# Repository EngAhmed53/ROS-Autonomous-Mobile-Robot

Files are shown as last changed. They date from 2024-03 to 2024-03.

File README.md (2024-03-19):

# Autonomous Navigation Mobile Robot

## Table of Contents

1. [Introduction](#introduction)
2. [Demo](#demo)
3. [Motivations](#motivations)
4. [Roadmap](#roadmap)
5. [Design](#design)
6. [Source Code](#source-code)
7. [License](#license)

## Introduction
This project is based on the Udacity Home Service Robot project, the final project of the Udacity Robotics Nanodegree.

## Demo
[Youtube video](https://youtu.be/6-blbdkCTCw?si=ebP5qN-LpaIK6vIa)

## Motivations
I start working on this project for several reasons:
1. To apply the knowledge I gained from the nanodegree to a real robot.
2. To enhance my understanding of ROS (Robot Operating System).
3. To observe the robot's behavior in real-world scenarios.

## Roadmap
To complete this project, I divided it into the following steps:
1. Set up Raspberry Pi.
2. Establish an SSH connection with Raspberry Pi.
3. Run RPLidar on Raspberry Pi and visualize its data on the remote machine.
4. Implement the Arduino ROS Bridge.
5. Implement the ROS control nodes on Raspberry Pi.
6. Test control nodes using keyboard input.
7. Design and build the robot chassis.
8. Configure the mapping nodes.
9. Test the mapping.
10. Configure the navigation nodes.
11. Test autonomous navigation.
12. Enhancements and fixes.

## Design
The robot is a differential drive robot with two wheels at the back and a caster wheel at the front.
The robot's base consists of three layers made from wooden material, separated by 45mm spacers. Each layer includes various components:
1. The bottom layer contains motors, an Arduino UNO board, an L298N motor driver, and a breadboard for component interconnection.
2. The middle layer houses the Raspberry Pi 3 Model B and an XL4015 5A Step Down Module to power the Raspberry Pi.
3. The upper layer hosts the RPLidar, the Raspberry Pi Camera v1, and a 12v battery.

The robot has three sensors:
1. Motor encoders
2. RPLidar
3. Camera

<p align="center" width="100%">
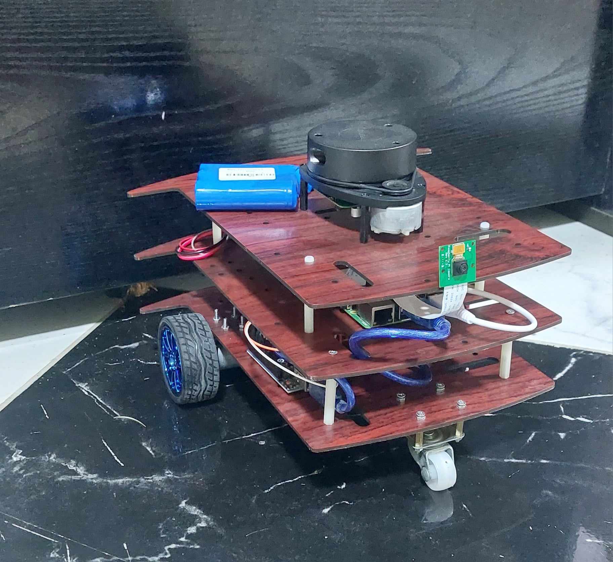
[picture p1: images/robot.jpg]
Robot
    
    <br>Robot Chassis
</p>

<p align="center" width="100%">
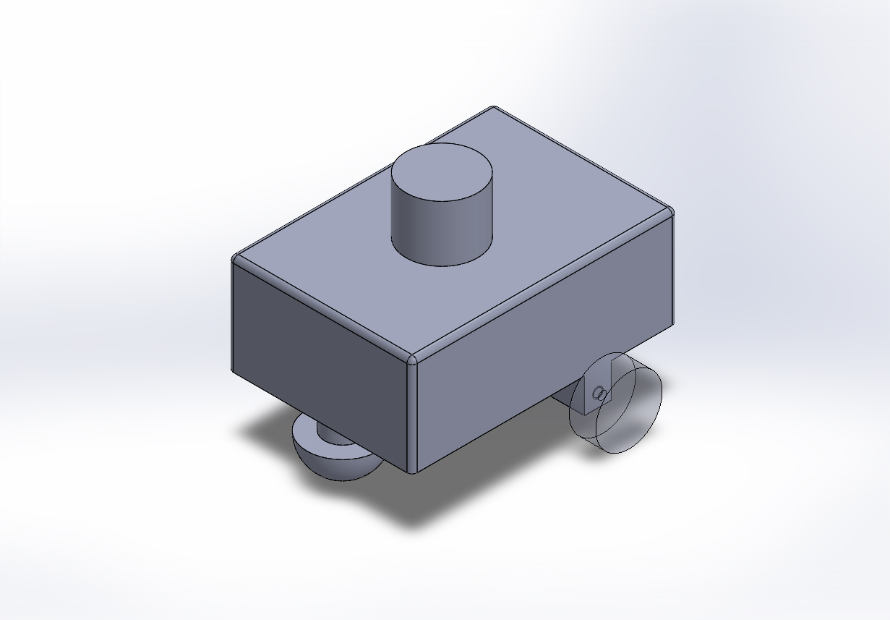
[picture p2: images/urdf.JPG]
    
    <br>Robot URDF
</p>

## Source Code

The robot uses a Raspberry Pi 3B. Due to its limited processing power, I've optimized its usage by offloading visualization and heavy computing tasks to a more powerful desktop computer. I used ROS networking to establish communication between the robot and the remote computer.

The Raspberry Pi manages the robot's sensors, such as the RPLidar and camera, by publishing their data to topics. Additionally, it controls the robot's movement by sending speed commands and receiving encoder readings from an Arduino board.

On the remote computer side, I handled visualization, mapping, and localization using SLAM (Simultaneous Localization and Mapping) and navigation nodes. For SLAM, I used the slam_gmapping node, while localization is achieved through the AMCL (Adaptive Monte Carlo Localization) node. Finally, autonomous navigation to the goal location is enabled using the move_base node.

The source code of the project is divided into three parts:
1. [The robot side](/Robot-Local): This code runs on the Raspberry Pi. The Raspberry Pi runs Ubuntu 20.04 with ROS Noetic [download link](https://learn.ubiquityrobotics.com/noetic_pi_image_downloads).
2. [The remote machine side](/Remote-Machine): This code runs on a remote computer.
3. [The Arduino ROS Bridge](https://github.com/EngAhmed53/ROS-Arduino-Bridge): This Arduino code runs on the Arduino UNO board. This code acts as a bridge between ROS and the motors.

## License
This project is licensed under the [MIT License](LICENSE).

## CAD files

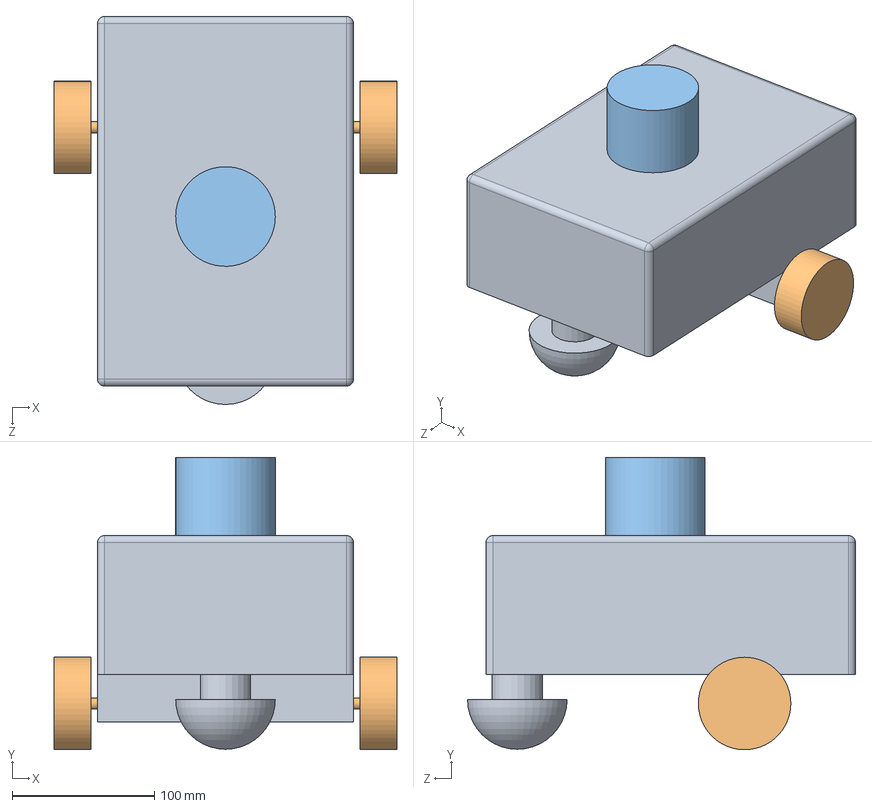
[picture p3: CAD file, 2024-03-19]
Design/robot_assem.SLDASM
241.0 x 205.5 x 272.6 mm
robot_base
robot_wheel x 2
rplidar_a1m12

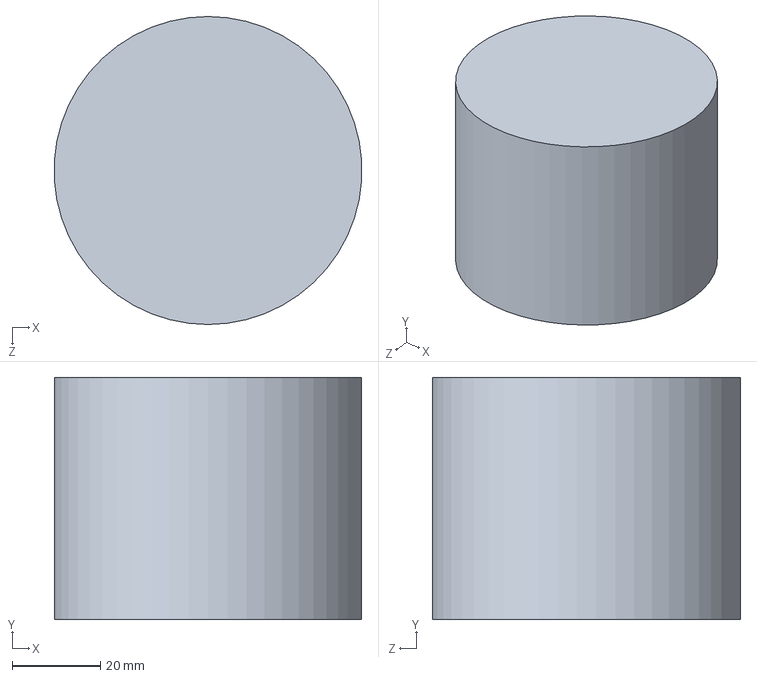
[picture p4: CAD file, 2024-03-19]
Design/rplidar_a1m12.SLDPRT
69.9 x 55.0 x 70.0 mm

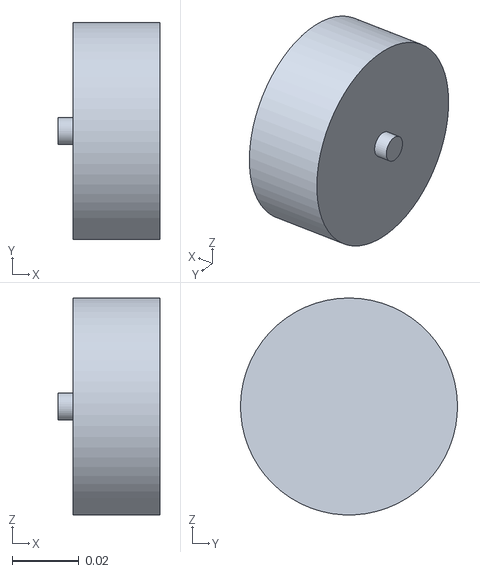
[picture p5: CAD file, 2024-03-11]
Robot-Local/src/my_robot/meshes/right_wheel.STL
0.0305 x 0.065 x 0.065

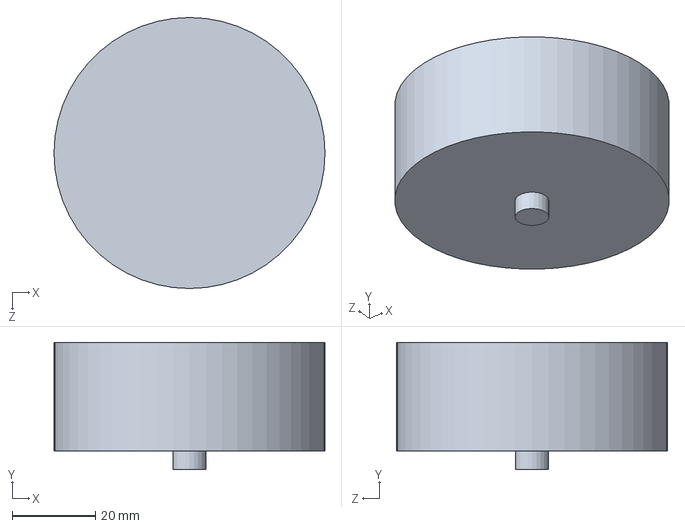
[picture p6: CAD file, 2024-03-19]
Design/robot_wheel.SLDPRT
65.0 x 30.5 x 65.0 mm

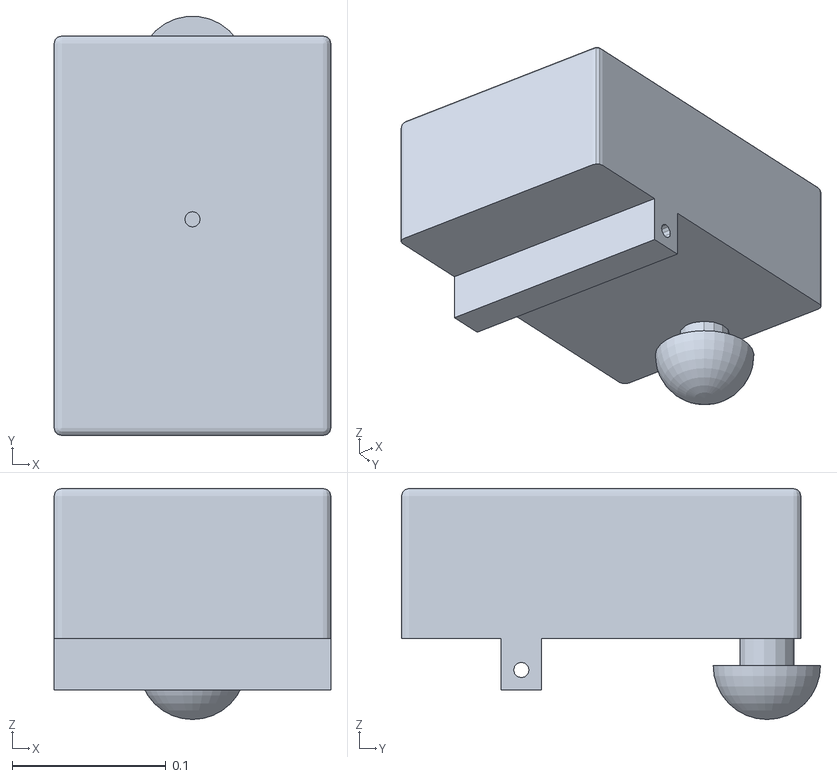
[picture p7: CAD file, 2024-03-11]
Robot-Local/src/my_robot/meshes/base_link.STL
0.18 x 0.272 x 0.15

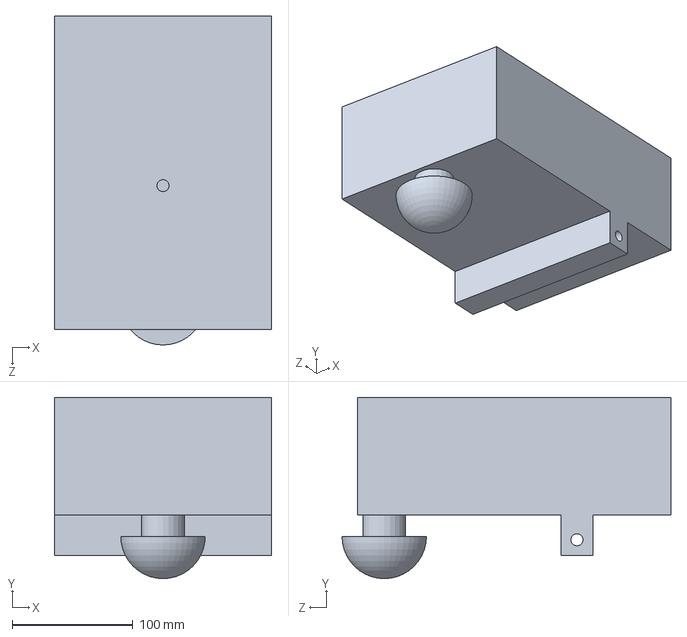
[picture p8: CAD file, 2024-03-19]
Design/robot_base.SLDPRT
180.0 x 150.2 x 272.6 mm

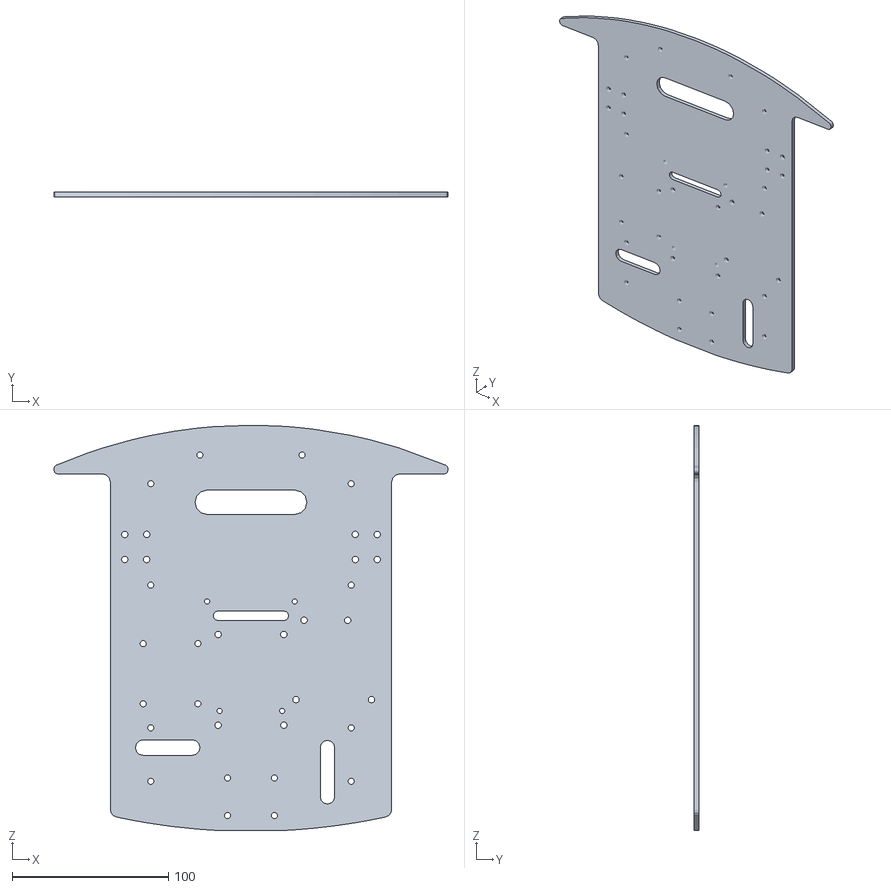
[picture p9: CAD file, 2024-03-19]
Design/robot_part_without_spacer.STL
252.0 x 3.00 x 259.3

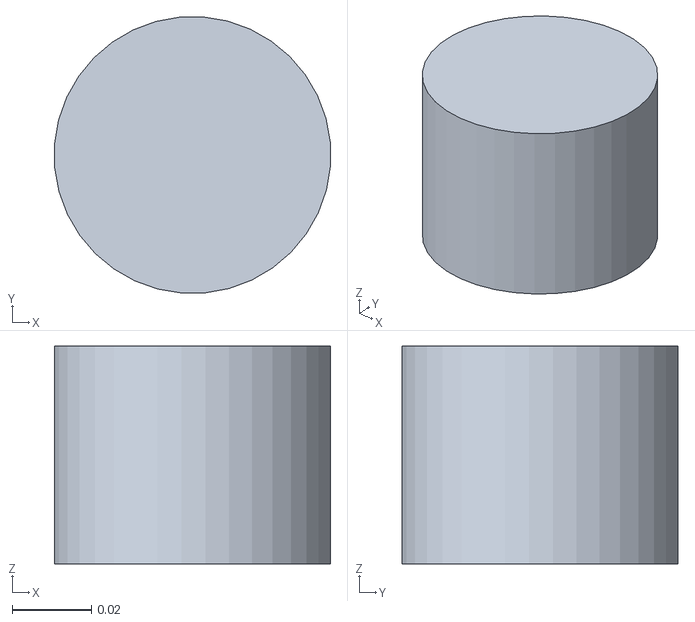
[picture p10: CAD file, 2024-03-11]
Robot-Local/src/my_robot/meshes/laser_link.STL
0.0698 x 0.0698 x 0.055

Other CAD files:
Robot-Local/src/my_robot/meshes/left_wheel.STL

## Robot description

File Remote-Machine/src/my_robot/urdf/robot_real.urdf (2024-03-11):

<?xml version="1.0" encoding="utf-8"?>
<!-- This URDF was automatically created by SolidWorks to URDF Exporter! Originally created by Stephen Brawner (brawner@gmail.com) 
     Commit Version: 1.6.0-4-g7f85cfe  Build Version: 1.6.7995.38578
     For more information, please see http://wiki.ros.org/sw_urdf_exporter -->
<robot name="robot_real">

  <link name="robot_footprint"></link>

  <joint name="robot_footprint_joint" type="fixed">
    <origin xyz="0 0 0" rpy="0 0 0" />
    <parent link="robot_footprint"/>
    <child link="base_link" />
  </joint>

  <link name="base_link">
    <inertial>
      <origin xyz="0 0.00086857 -0.052452" rpy="0 0 0" />
      <mass value="4.8015" />
      <inertia ixx="0.031989" ixy="-1.3236E-18" ixz="-6.8277E-21" iyy="0.017464" iyz="0.00037688" izz="0.039875" />
    </inertial>
    <visual>
      <origin xyz="0 0 0" rpy="0 0 0" />
      <geometry>
        <mesh filename="package://my_robot/meshes/base_link.STL" />
      </geometry>
      <material name="">
        <color rgba="0.79216 0.81961 0.93333 1" />
      </material>
    </visual>
    <collision>
      <origin xyz="0 0 0" rpy="0 0 0" />
      <geometry>
        <mesh filename="package://my_robot/meshes/base_link.STL" />
      </geometry>
    </collision>
  </link>
  <link name="laser_link">
    <inertial>
      <origin xyz="9.8765E-13 -7.5229E-13 -0.0275" rpy="0 0 0" />
      <mass value="0.21166" />
      <inertia ixx="0.00011818" ixy="1.6676E-21" ixz="-2.1229E-36" iyy="0.00011818" iyz="-3.1058E-21" izz="0.00012964" />
    </inertial>
    <visual>
      <origin xyz="0 0 0" rpy="0 0 0" />
      <geometry>
        <mesh filename="package://my_robot/meshes/laser_link.STL" />
      </geometry>
      <material name="">
        <color rgba="0.79216 0.81961 0.93333 1" />
      </material>
    </visual>
    <collision>
      <origin xyz="0 0 0" rpy="0 0 0" />
      <geometry>
        <mesh filename="package://my_robot/meshes/laser_link.STL" />
      </geometry>
    </collision>
  </link>
  <joint name="laser_joint" type="fixed">
    <origin xyz="0 0.010725 0.046" rpy="0 0 0" />
    <parent link="base_link" />
    <child link="laser_link" />
    <axis xyz="0 0 0" />
  </joint>
  <link name="left_wheel">
    <inertial>
      <origin xyz="0.01304 0 0" rpy="0 0 0" />
      <mass value="0.086502" />
      <inertia ixx="4.5566E-05" ixy="7.1534E-20" ixz="7.1695E-20" iyy="2.7696E-05" iyz="2.1146E-34" izz="2.7696E-05" />
    </inertial>
    <visual>
      <origin xyz="0 0 0" rpy="0 0 0" />
      <geometry>
        <mesh filename="package://my_robot/meshes/left_wheel.STL" />
      </geometry>
      <material name="">
        <color rgba="0.79216 0.81961 0.93333 1" />
      </material>
    </visual>
    <collision>
      <origin xyz="0 0 0" rpy="0 0 0" />
      <geometry>
        <mesh filename="package://my_robot/meshes/left_wheel.STL" />
      </geometry>
    </collision>
  </link>
  <joint name="left_wheel_joint" type="continuous">
    <origin xyz="-0.1205 -0.051915 -0.118" rpy="0 0 0" />
    <parent link="base_link" />
    <child link="left_wheel" />
    <axis xyz="1 0 0" />
    <limit effort="0" velocity="2" />
  </joint>
  <link name="right_wheel">
    <inertial>
      <origin xyz="-0.01304 -4.4409E-16 2.2204E-16" rpy="0 0 0" />
      <mass value="0.086502" />
      <inertia ixx="4.5566E-05" ixy="1.7026E-19" ixz="-7.1695E-20" iyy="2.7696E-05" iyz="-7.8374E-34" izz="2.7696E-05" />
    </inertial>
    <visual>
      <origin xyz="0 0 0" rpy="0 0 0" />
      <geometry>
        <mesh filename="package://my_robot/meshes/right_wheel.STL" />
      </geometry>
      <material name="">
        <color rgba="0.79216 0.81961 0.93333 1" />
      </material>
    </visual>
    <collision>
      <origin xyz="0 0 0" rpy="0 0 0" />
      <geometry>
        <mesh filename="package://my_robot/meshes/right_wheel.STL" />
      </geometry>
    </collision>
  </link>
  <joint name="right_wheel_joint" type="continuous">
    <origin xyz="0.1205 -0.051915 -0.118" rpy="0 0 0" />
    <parent link="base_link" />
    <child link="right_wheel" />
    <axis xyz="1 0 0" />
    <limit effort="0" velocity="2" />
  </joint>
</robot>

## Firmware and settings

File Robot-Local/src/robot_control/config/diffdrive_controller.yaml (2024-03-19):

mobile_robot:

    joints_update:
      type: joint_state_controller/JointStateController
      publish_rate: 50

    mobile_base_controller:
      type        : "diff_drive_controller/DiffDriveController"
      left_wheel  : 'left_wheel_joint'
      right_wheel : 'right_wheel_joint'
      publish_rate: 50.0               # default: 50
      pose_covariance_diagonal : [0.001, 0.001, 1000000.0, 1000000.0, 1000000.0, 1000.0]
      twist_covariance_diagonal: [0.001, 0.001, 1000000.0, 1000000.0, 1000000.0, 1000.0]

      # Wheel separation and diameter. These are both optional.
      # diff_drive_controller will attempt to read either one or both from the
      # URDF if not specified as a parameter
      wheel_separation : 0.214
      wheel_radius : 0.0325

      # Wheel separation and radius multipliers
      wheel_separation_multiplier: 1.0 # default: 1.0
      wheel_radius_multiplier    : 1.0 # default: 1.0

      # Velocity commands timeout [s], default 0.5
      cmd_vel_timeout: 0.25

      # Base frame_id
      base_frame_id: "robot_footprint"

      # Velocity and acceleration limits
      # Whenever a min_* is unspecified, default to -max_*
      linear:
        x:
          has_velocity_limits    : true
          max_velocity           : 0.80  # m/s
          min_velocity           : -0.80 # m/s
          has_acceleration_limits: true
          max_acceleration       : 0.6  # m/s^2
          min_acceleration       : -0.6 # m/s^2
          has_jerk_limits        : false
          max_jerk               : 2.0  # m/s^3
      angular:
        z:
          has_velocity_limits    : true
          max_velocity           : 4.0  # rad/s
          has_acceleration_limits: true
          max_acceleration       : 2.5    # rad/s^2
          has_jerk_limits        : false
          max_jerk               : 5 # rad/s^3

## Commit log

2024-03-11 add my_robot pkg
    [base_link.STL, laser_link.STL, left_wheel.STL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]
2024-03-19 Add robot src folder
    [base_link.STL, diffdrive_controller.yaml, joint_limits.yaml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]
2024-03-19 Add solidworks files
    [robot_assem.SLDASM, robot_base.SLDPRT, robot_part_without_spacer.STL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]
